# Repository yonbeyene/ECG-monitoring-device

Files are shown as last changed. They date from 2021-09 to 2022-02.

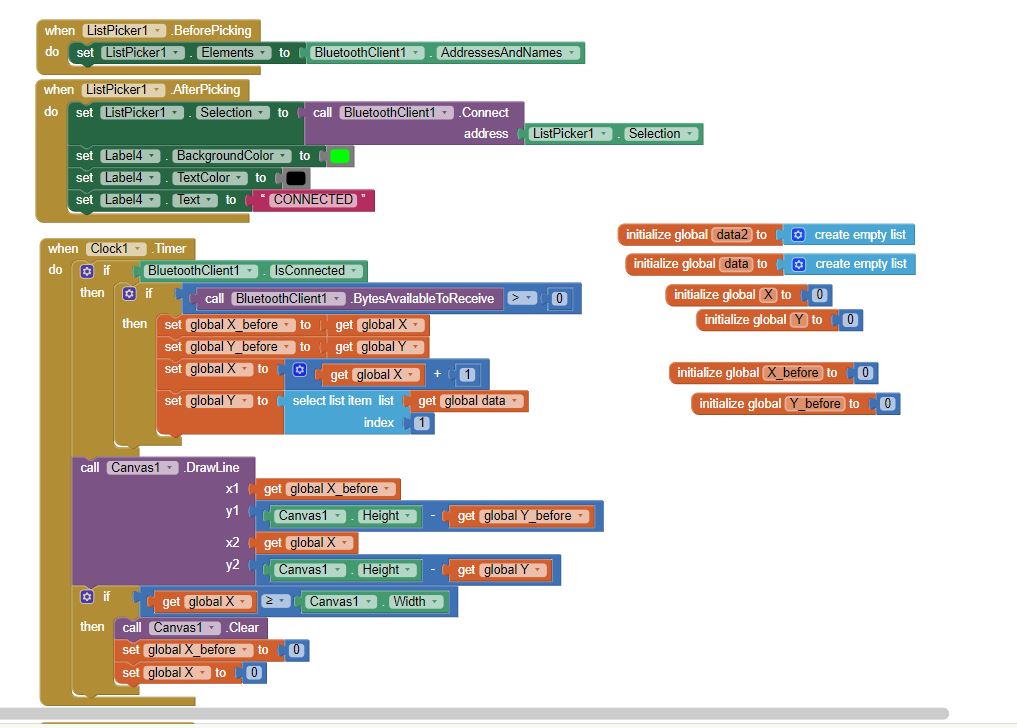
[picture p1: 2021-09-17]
Mobile Application/app.JPG

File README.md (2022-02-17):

# ECG-monitoring-device
In this project, a flexible wireless electrocardiogram (ECG) monitoring device was developed using carbon nanotube based dry electrodes and a flexible printed circuit board (PCB) module integrated into a fabric chest belt. The PCB board is designed using Autodesk Eagle. An android mobile application to display an ECG graph is also developed using MIT App Inventor 2 IDE. 

The paper for the project is published at the 2021 IEEE sensors conference. Here is the link for the publication:
https://ieeexplore.ieee.org/abstract/document/9639596

# PCB Board
Board


# Circuit Schematic
ECG Sch2

# App Demo
448D264C-C142-4223-B12F-5A788E09FB86

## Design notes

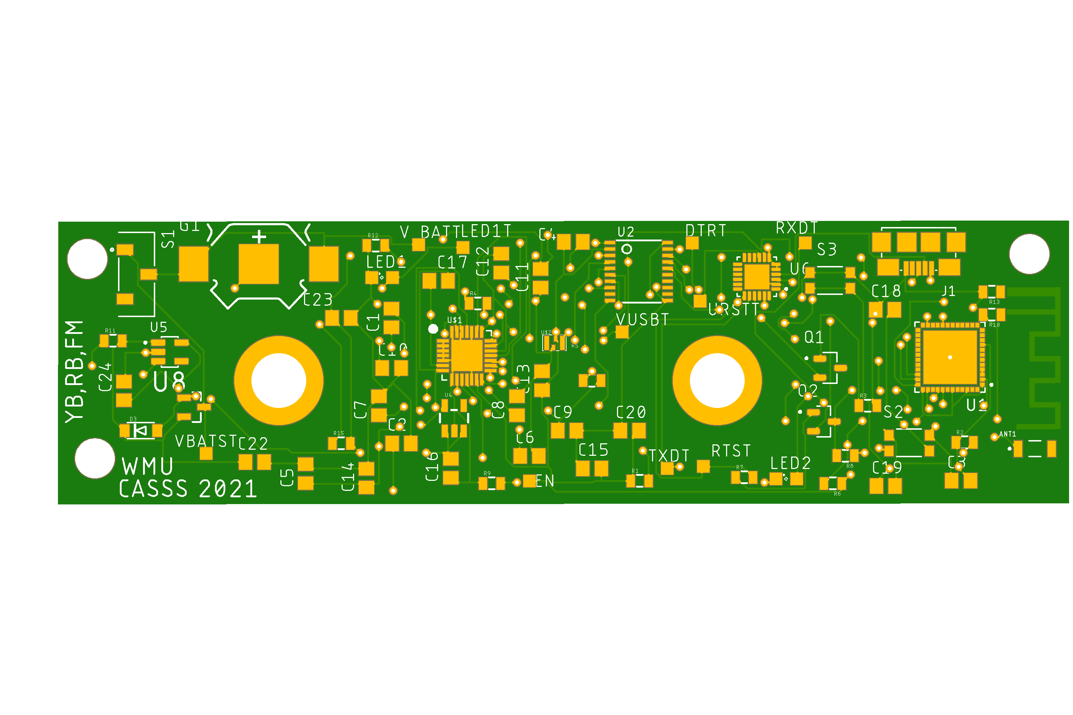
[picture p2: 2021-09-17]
PCB/ECG.png

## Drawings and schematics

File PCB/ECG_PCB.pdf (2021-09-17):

# 2 AGND

# 5 EGGP

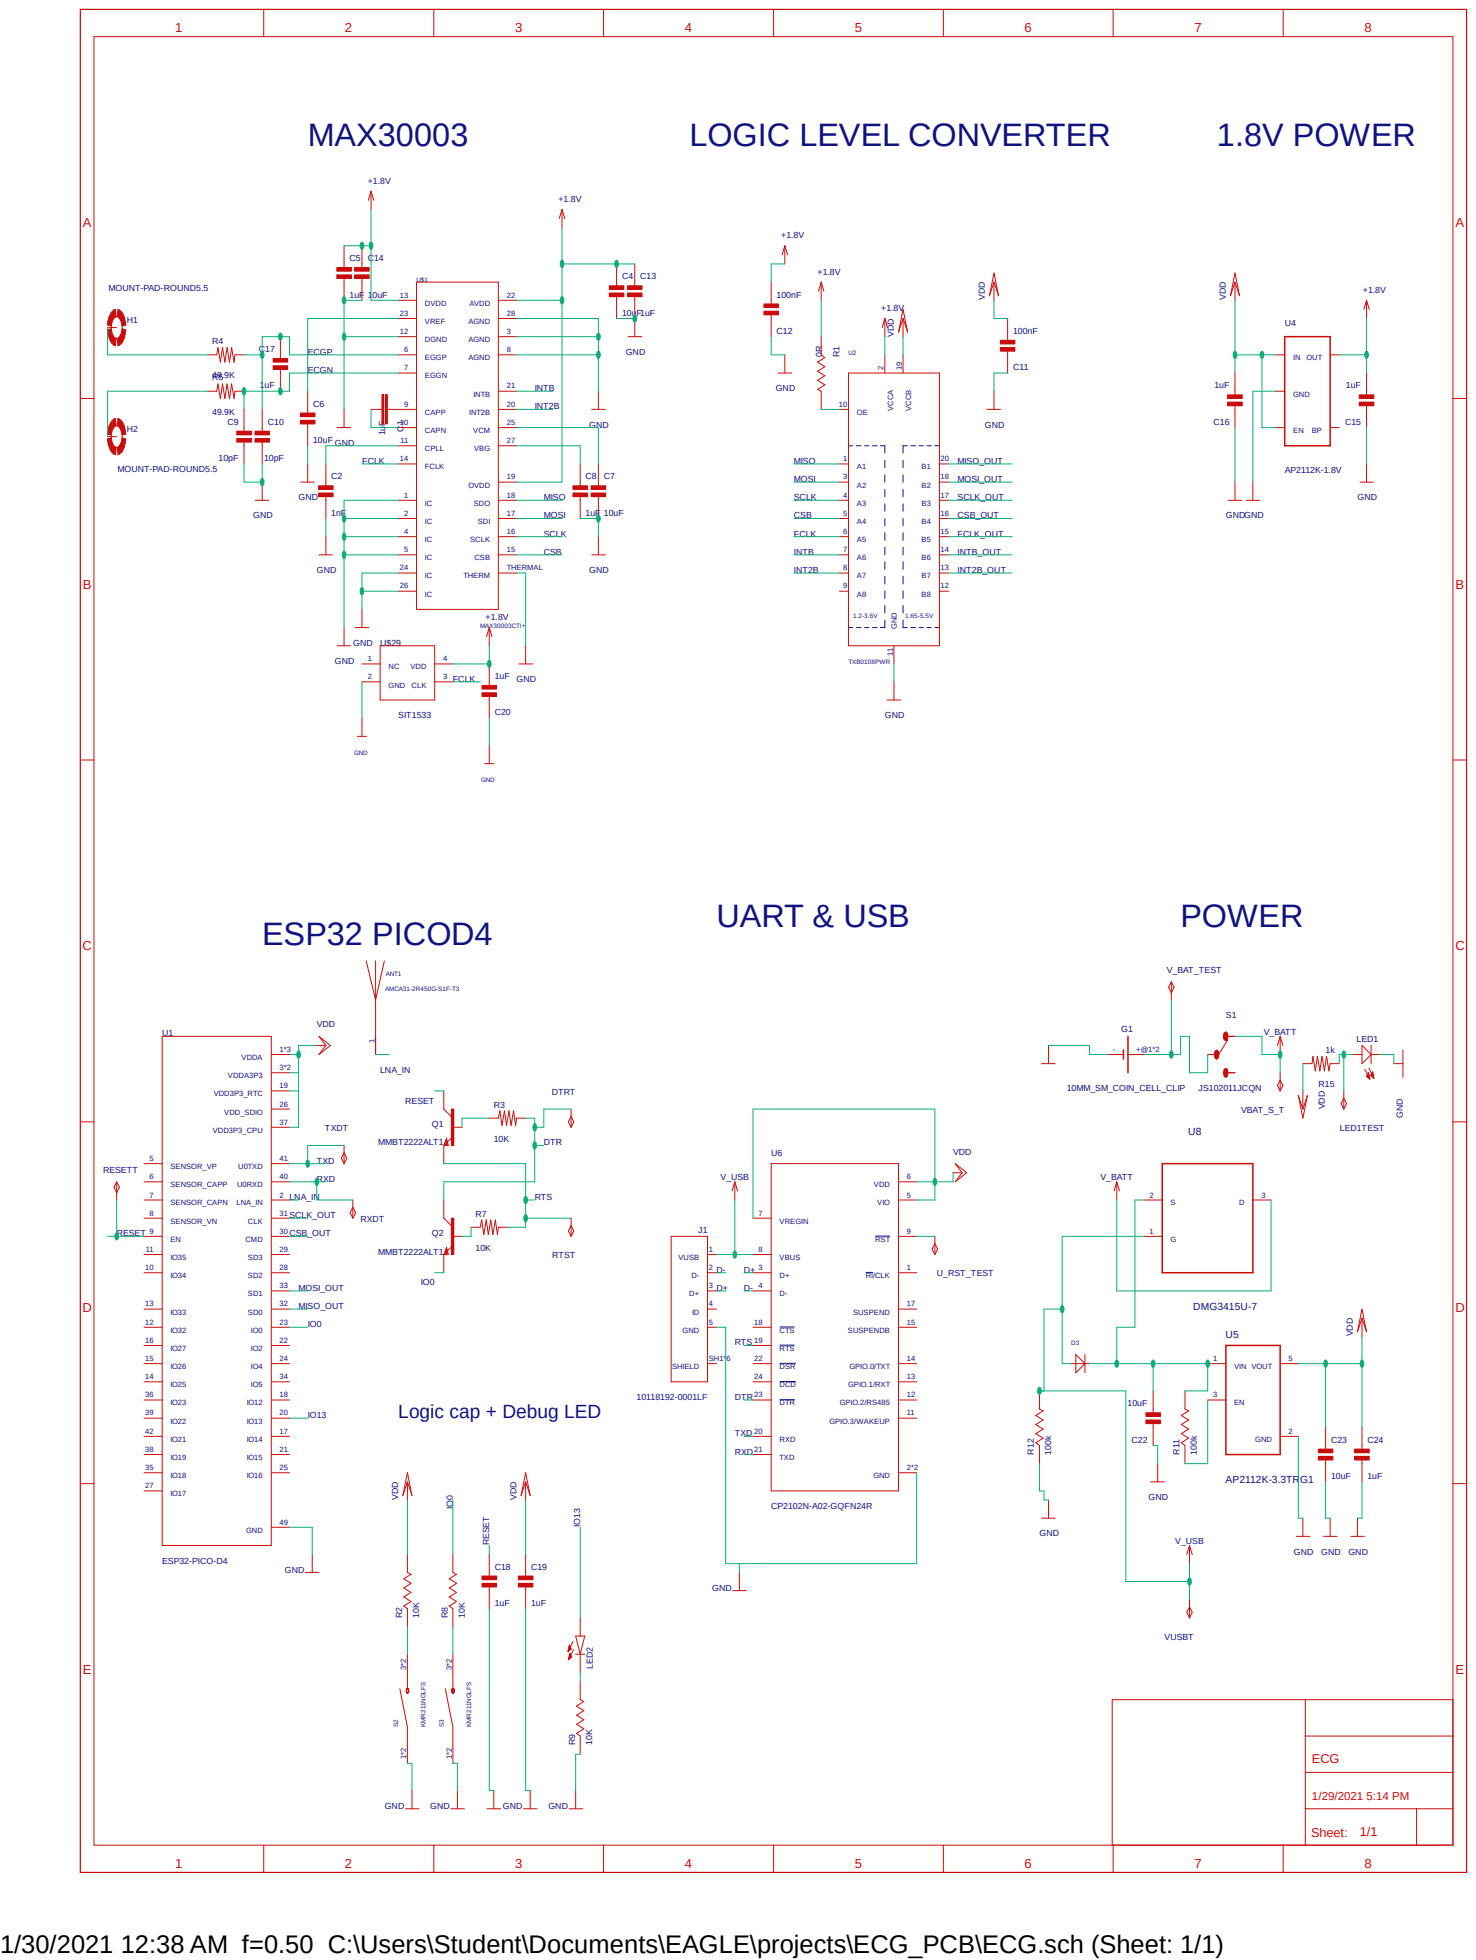
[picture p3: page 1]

Logic cap + Debug LED

1/30/2021 12:38 AM f=0.50 C:\Users\Student\Documents\EAGLE\projects\ECG_PCB\ECG.sch (Sheet: 1/1)

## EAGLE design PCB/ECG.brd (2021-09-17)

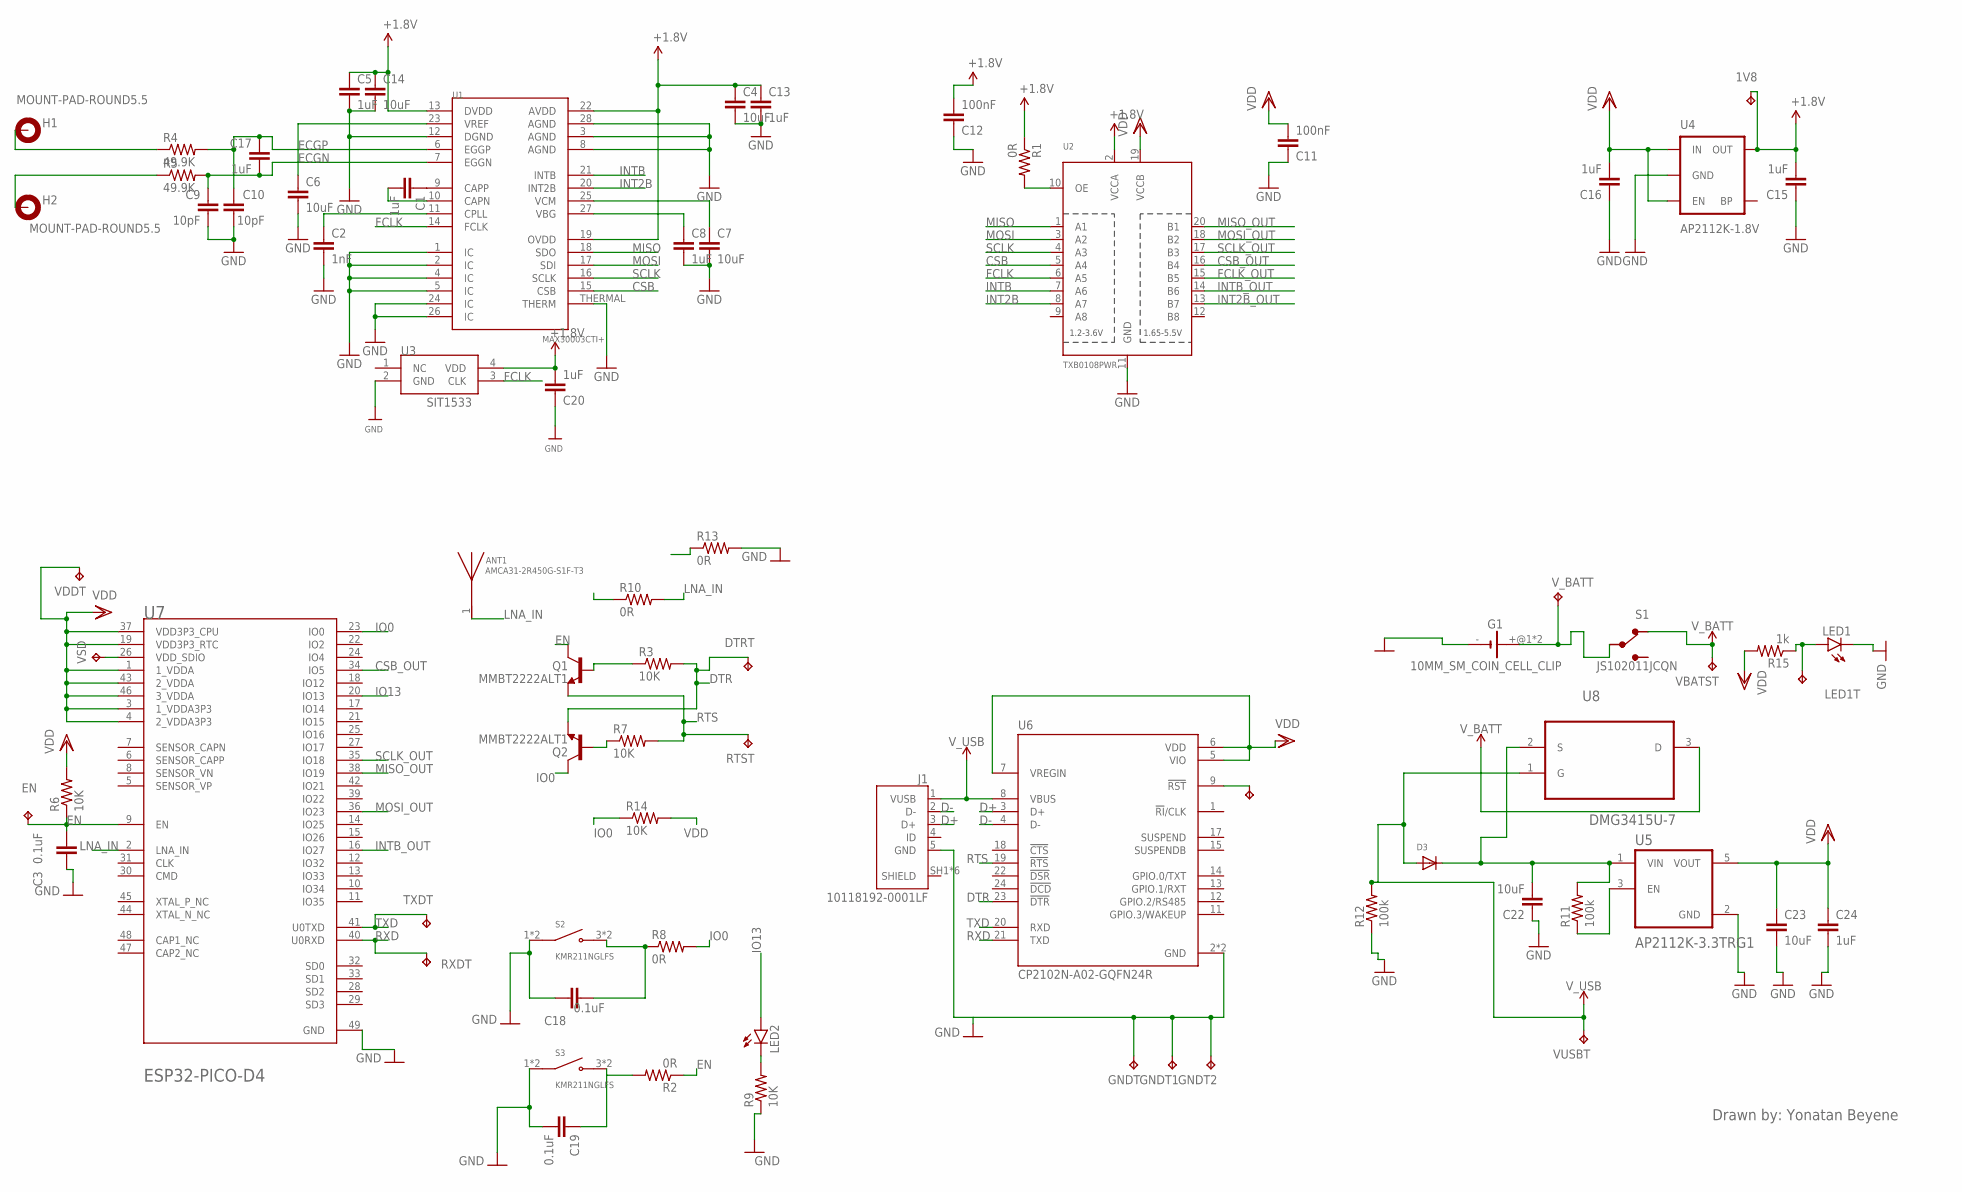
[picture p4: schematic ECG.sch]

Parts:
1V8: TPTP12SQ; TP12SQ
ANT1: AMCA31-2R450G-S1F-T3; ANT_AMCA31-2R450G-S1F-T3
C1, C5, C8, C13, C15, C16, C17, C20, C24: 1uF; C0805
C2: 1nF; C0805
C3, C18, C19: 0.1uF; C0805
C4, C6, C7, C14, C22, C23: 10uF; C0805
C9, C10: 10pF; C0805
C11, C12: 100nF; C0805
D3: DIODE_SOD-123FL; SOD-123FL
DTRT: TPTP12SQ; TP12SQ
EN: TPTP12SQ; TP12SQ
G1: 10MM_SM_COIN_CELL_CLIP
GNDT, GNDT1, GNDT2: TPTP12SQ; TP12SQ
H1, H2: MOUNT-PAD-ROUND5.5; 5,5-PAD
J1: 10118192-0001LF; AMPHENOL_10118192-0001LF
LED1, LED2: LEDSML0805; SML0805
LED1T: TPTP12SQ; TP12SQ
Q1, Q2: MMBT2222ALT1; SOT95P237X111-3N
R1, R2, R8, R10, R13: 0R; 0805
R3, R6, R7, R9, R14: 10K; 0805
R4, R5: 49.9K; 0805
R11, R12: 100k; 0805
R15: 1k; 0805
RTST: TPTP12SQ; TP12SQ
RXDT: TPTP12SQ; TP12SQ
S1: JS102011JCQN; SW_JS102011JCQN
S2, S3: KMR211NGLFS; SW_KMR211NGLFS
TXDT: TPTP12SQ; TP12SQ
U1: MAX30003CTI+; QFN-28
U2: TXB0108PWR; TSSOP20
U3: SIT1533
U4: AP2112K-1.8V; SOT23-5
U5: AP2112K-3.3TRG1; SOT95P285X140-5N
U6: CP2102N-A02-GQFN24R; QFN50P400X400X80-25N
U7: ESPRESSIF_SYSTEMS_ESP32-PICO-D4ESPRESSIF_SYSTEMS_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; ESPRESSIF_SYSTEMS_ESP32-PICO-D4_0
U8: DMG3415U-7; SOT95P240X105-3N
URSTT: TPTP12SQ; TP12SQ
VBATST: TPTP12SQ; TP12SQ
VDDT: TPTP12SQ; TP12SQ
VSD: TPTP12SQ; TP12SQ
VUSBT: TPTP12SQ; TP12SQ
V_BATT: TPTP12SQ; TP12SQ

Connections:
+1.8V: 1V8.TP, C4.1, C5.1, C12.2, C13.1, C14.1, C15.2, C20.2, R1.1, U1.13 (DVDD), U1.19 (OVDD), U1.22 (AVDD), U2.2 (VCCA), U3.4 (VDD), U4.5 (OUT)
CSB: U1.15 (CSB), U2.5 (A4)
CSB_OUT: U2.16 (B4), U7.34 (IO5)
D+: J1.3 (D+), U6.3 (D+)
D-: J1.2 (D-), U6.4 (D-)
DTR: DTRT.TP, Q2.2 (E), R3.2, U6.23 (!DTR)
ECGN: C9.1, C17.2, R5.2, U1.7 (EGGN)
ECGP: C10.1, C17.1, R4.2, U1.6 (EGGP)
EN: C3.2, EN.TP, Q1.3 (C), R2.1, R6.1, U7.9 (EN)
FCLK: U1.14 (FCLK), U2.6 (A5), U3.3 (CLK)
FCLK_OUT: U2.15 (B5)
GND: C2.2, C3.1, C4.2, C5.2, C6.2, C7.2, C8.2, C9.2, C10.2, C11.1, C12.1, C13.2, C14.2, C15.1, C16.1, C18.1, C19.2, C20.1, C22.1, C23.2, C24.2, G1.-, GNDT.TP, GNDT1.TP, GNDT2.TP, J1.5 (GND), LED1.C, R9.1, R12.1, R13.2, S2.1 (COM), S2.2 (COM), S3.1 (COM), S3.2 (COM), U1.1 (IC), U1.2 (IC), U1.3 (AGND), U1.4 (IC), U1.5 (IC), U1.8 (AGND), U1.12 (DGND), U1.24 (IC), U1.26 (IC), U1.28 (AGND), U1.THERMAL (THERM), U2.11 (GND), U3.2 (GND), U4.2 (GND), U5.2 (GND), U6.2 (GND), U6.25 (GND), U7.49 (GND)
INT2B: U1.20 (INT2B), U2.8 (A7)
INT2B_OUT: U2.13 (B7)
INTB: U1.21 (INTB), U2.7 (A6)
INTB_OUT: U2.14 (B6), U7.16 (IO27)
IO0: Q2.3 (C), R8.2, R14.1, U7.23 (IO0)
IO13: LED2.A, U7.20 (IO13)
LNA_IN: ANT1.1, R10.2, U7.2 (LNA_IN)
MISO: U1.18 (SDO), U2.1 (A1)
MISO_OUT: U2.20 (B1), U7.38 (IO19)
MOSI: U1.17 (SDI), U2.3 (A2)
MOSI_OUT: U2.18 (B2), U7.36 (IO23)
unnamed: H1.B5,5, R4.1
unnamed: C6.1, U1.23 (VREF)
unnamed: C1.1, U1.9 (CAPP)
unnamed: H2.B5,5, R5.1
unnamed: R1.2, U2.10 (OE)
unnamed: C1.2, U1.10 (CAPN)
unnamed: C2.1, U1.11 (CPLL)
unnamed: Q1.1 (B), R3.1
unnamed: U7.26 (VDD_SDIO), VSD.TP
unnamed: Q2.1 (B), R7.1
unnamed: C18.2, R8.1, S2.3 (NO), S2.4 (NO)
unnamed: C8.1, U1.27 (VBG)
unnamed: LED2.C, R9.2
unnamed: LED1.A, LED1T.TP, R15.1
unnamed: U6.9 (!RST), URSTT.TP
unnamed: C19.1, R2.2, S3.3 (NO), S3.4 (NO)
unnamed: G1.+@1 (+), G1.+@2 (+), S1.2, V_BATT.TP
unnamed: R11.1, U5.3 (EN)
unnamed: C22.2, D3.C, R11.2, U5.1 (VIN), U8.2 (S)
RTS: Q1.2 (E), R7.2, RTST.TP, U6.19 (!RTS)
RXD: RXDT.TP, U6.21 (TXD), U7.40 (U0RXD)
SCLK: U1.16 (SCLK), U2.4 (A3)
SCLK_OUT: U2.17 (B3), U7.35 (IO18)
TXD: TXDT.TP, U6.20 (RXD), U7.41 (U0TXD)
VCM: C7.1, U1.25 (VCM)
VDD: C11.2, C16.2, C23.1, C24.1, R6.2, R14.2, R15.2, U2.19 (VCCB), U4.1 (IN), U4.3 (EN), U5.5 (VOUT), U6.5 (VIO), U6.6 (VDD), U6.7 (VREGIN), U7.1 (1_VDDA), U7.3 (1_VDDA3P3), U7.4 (2_VDDA3P3), U7.19 (VDD3P3_RTC), U7.37 (VDD3P3_CPU), U7.43 (2_VDDA), U7.46 (3_VDDA), VDDT.TP
V_BATT: S1.1, U8.3 (D), VBATST.TP
V_USB: D3.A, J1.1 (VUSB), R12.2, U6.8 (VBUS), U8.1 (G), VUSBT.TP

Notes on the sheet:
Drawn by: Yonatan Beyene

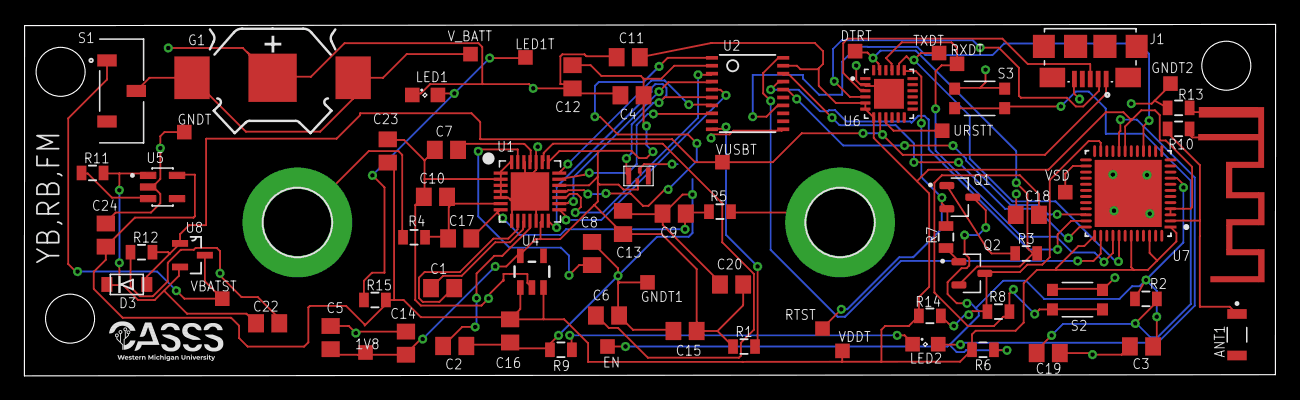
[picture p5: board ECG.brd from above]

Board: 2 copper layers, 102.5 x 28.8 mm, 75 parts (0 on the bottom side), 49 nets.

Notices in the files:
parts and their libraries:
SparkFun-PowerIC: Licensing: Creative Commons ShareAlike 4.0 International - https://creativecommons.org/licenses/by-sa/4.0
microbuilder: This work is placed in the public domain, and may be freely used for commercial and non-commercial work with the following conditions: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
